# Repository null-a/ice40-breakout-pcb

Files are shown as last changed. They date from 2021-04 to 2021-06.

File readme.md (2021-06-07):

# Lattice iCE40 HX4K breakout / dev board

## Introduction

This KiCAD project contains the design of a break out / dev board for
a Lattice iCE40 HX4K FPGA.

I'm a novice at PCB design, so please don't assume anything here
represents good practice. I was motivated to tackle this after seeing
Matt Venn's [iCE40 board](https://github.com/mattvenn/first-fpga-pcb).
Some elements of the design are based on
the [TinyFPGA BX](https://github.com/tinyfpga/TinyFPGA-BX).

## Features

* SPI flash for configuration.
* On-board clock.
* Powered by 5v from a micro USB connector. Regulators for 3.3v and
  1.2v. Power LED.
* Single output LED.
* 72 GPIO pins broken out. sysCONFIG pins broken out for programming
  the flash. Cold boot config pins broken out.
* The USB data lines are connected to the FPGA. This makes it possible
  to program the board directly over USB using e.g. the TinyFPGA
  bootloader.
* 2 layer PCB.
* Designed for hand assembly.

## Project Log

* 2021-06-07: I now have the
  [TinyFPGA bootloader](https://github.com/tinyfpga/TinyFPGA-Bootloader) working.
* 2021-05-22: Confirmed that I can blink the on-board LED using the
  FPGA. I'm currently using an external programmer to load the
  configuration into the on-board flash. (See [blinky](blinky).)
* 2021-05-12: First
  board
  [assembled](https://www.dropbox.com/s/xi2ujczmzbuk978/?raw=1).
* 2021-05-10: Prototype boards received.
* 2021-04-22:
  [Revision A](https://www.dropbox.com/s/bwuf1rviyvo0iy6/?raw=1) of
  the board completed. Prototype boards ordered.

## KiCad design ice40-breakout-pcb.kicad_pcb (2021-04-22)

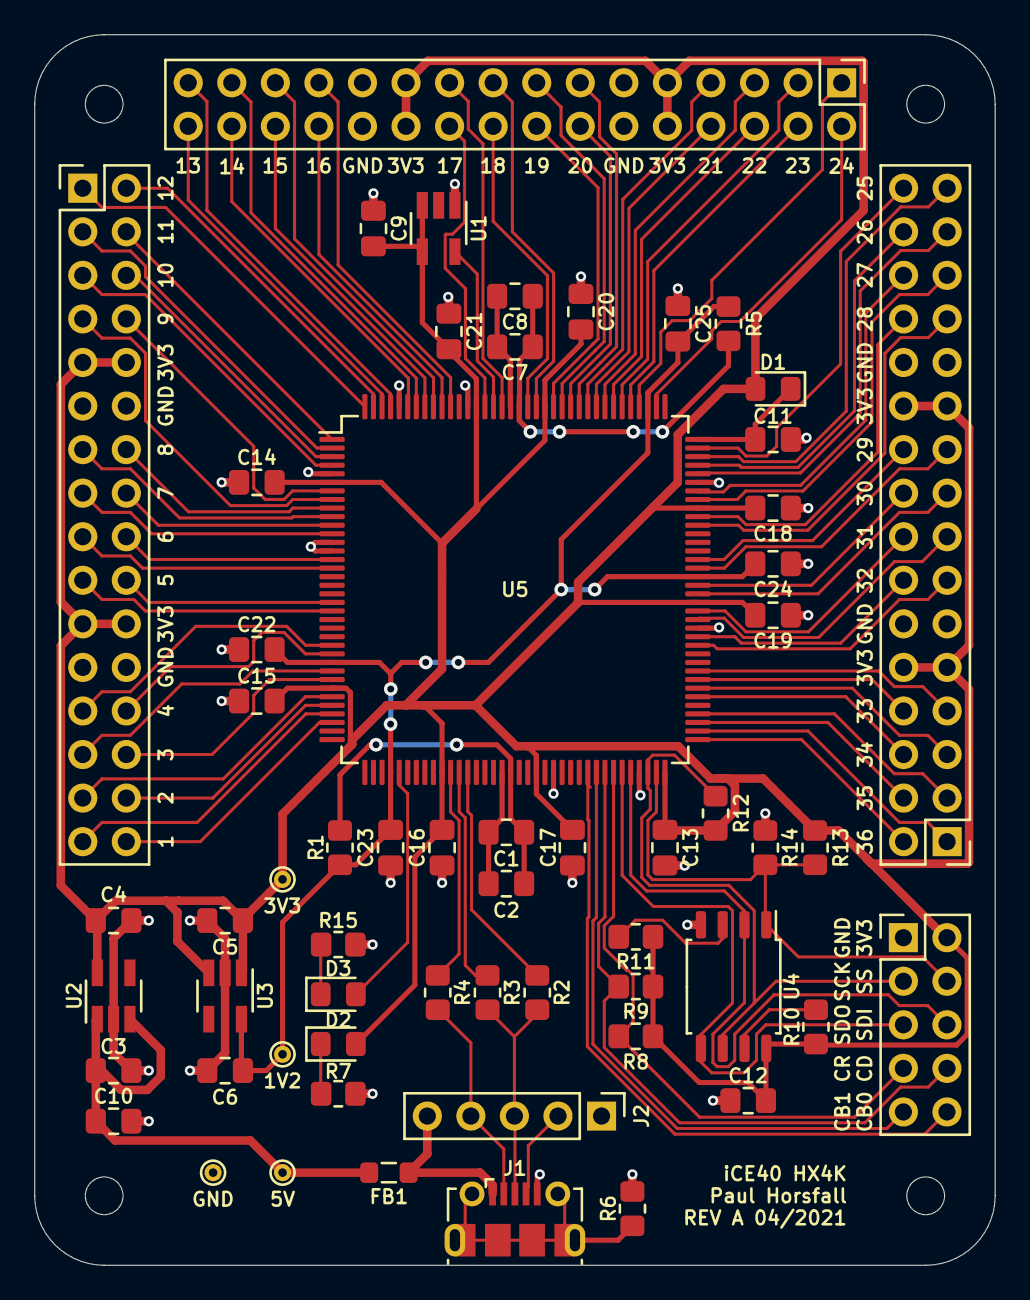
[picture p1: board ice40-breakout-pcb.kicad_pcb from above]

Board: 2 copper layers, 56.0 x 71.8 mm, 59 parts (0 on the bottom side), 103 nets.

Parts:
C1, C7, C10: 10uF; C_0805_2012Metric_Pad1.18x1.45mm_HandSolder
C2, C8, C9, C11, C12, C13, C14, C15, C16, C17, C18, C19, C20, C21, C22, C23, C24, C25: 0.1uF; C_0805_2012Metric_Pad1.18x1.45mm_HandSolder
C3, C4, C5, C6: 1uF; C_0805_2012Metric_Pad1.18x1.45mm_HandSolder
D1: Short; D_0805_2012Metric_Pad1.15x1.40mm_HandSolder
D2, D3: LED; LED_0805_2012Metric_Pad1.15x1.40mm_HandSolder
FB1: 30 ohm; L_0805_2012Metric_Pad1.05x1.20mm_HandSolder
J1: USB_B_Micro; USB_Micro-B_Molex-105017-0001
J2: USB_Break_Out; PinHeader_1x05_P2.54mm_Vertical
J3, J4, J5: Conn_02x16_Odd_Even; PinHeader_2x16_P2.54mm_Vertical
J6: Conn_02x04_Odd_Even; PinHeader_2x05_P2.54mm_Vertical
R1, R5: 100; R_0805_2012Metric_Pad1.20x1.40mm_HandSolder
R2: 1.5K; R_0805_2012Metric_Pad1.20x1.40mm_HandSolder
R3, R4: 68; R_0805_2012Metric_Pad1.20x1.40mm_HandSolder
R6, R10, R11: 0; R_0805_2012Metric_Pad1.20x1.40mm_HandSolder
R7, R15: 330; R_0805_2012Metric_Pad1.20x1.40mm_HandSolder
R8, R9, R12, R13: 10K; R_0805_2012Metric_Pad1.20x1.40mm_HandSolder
R14: NP; R_0805_2012Metric_Pad1.20x1.40mm_HandSolder
TP1, TP2, TP3, TP4: TestPoint; TestPoint_THTPad_D1.0mm_Drill0.5mm
U1: SIT2001BI-S2-33E-12.000000G; SOT-23-5_HandSoldering
U2: TLV73333PDBV; SOT-23-5_HandSoldering
U3: TLV73312PDBV; SOT-23-5_HandSoldering
U4: AT25SF081-SHD-X; SOIC-8_5.23x5.23mm_P1.27mm
U5: ICE40HX4K-TQ144; TQFP-144_20x20mm_P0.5mm

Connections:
+1V2: C6.1, C22.2, C23.2, C24.2, C25.2, R1.1, R5.1, TP3.1, U3.5, U5.27, U5.40, U5.92, U5.111
+3V3: C4.1, C5.1, C9.2, C12.2, C13.1, C14.2, C15.2, C16.2, C17.2, C18.2, C19.2, C20.2, C21.2, D1.2, D2.2, J3.9, J3.10, J3.21, J3.22, J4.9, J4.10, J4.21, J4.22, J5.9, J5.10, J5.21, J5.22, J6.2, R8.1, R9.1, R10.1, R11.1, R12.1, R13.1, TP2.1, U1.3, U1.4, U2.5, U3.1, U3.3, U4.8, U5.6, U5.30, U5.46, U5.57, U5.72, U5.89, U5.100, U5.123, U5.131
+5V: C3.1, C10.1, FB1.2, TP1.1, U2.1, U2.3
CDONE: J6.8, R9.2, U5.65
CLK: U1.5, U5.129
CRESET: J6.7, R8.2, U5.66
GND: C3.2, C4.2, C5.2, C6.2, C9.1, C10.2, C11.2, C12.1, C13.2, C14.1, C15.1, C16.1, C17.1, C18.1, C19.1, C20.1, C21.1, C22.1, C23.1, C24.1, C25.1, J1.5, J2.1, J3.11, J3.12, J3.23, J3.24, J4.11, J4.12, J4.23, J4.24, J5.11, J5.12, J5.23, J5.24, J6.1, R6.2, R7.2, R14.1, R15.2, TP4.1, U1.1, U2.2, U3.2, U4.4, U5.5, U5.13, U5.14, U5.59, U5.69, U5.86, U5.103, U5.132, U5.140
GNDPLL0: C1.2, C2.2, U5.53
GNDPLL1: C7.2, C8.2, U5.127
LED: D3.2, U5.41
unnamed: D2.1, R7.1
unnamed: D3.1, R15.1
unnamed: FB1.1, J1.1, J2.5
unnamed: J1.2, J2.4, R4.2
unnamed: J1.3, J2.3, R2.2, R3.2
unnamed: J1.4, J2.2
unnamed: J1.6, R6.1
unnamed: R10.2, U4.7
unnamed: R11.2, U4.3
SPI_MISO: J6.6, U4.2, U5.68
SPI_MOSI: J6.5, U4.5, U5.67
SPI_SCK: J6.3, R12.2, U4.6, U5.70
SPI_SS: J6.4, R13.2, R14.2, U4.1, U5.71
USB_N: R4.1, U5.47
USB_P: R3.1, U5.48
USB_PU: R2.1, U5.49
VCCPLL0: C1.1, C2.1, R1.2, U5.54
VCCPLL1: C7.1, C8.1, R5.2, U5.126
VPP_2V5: C11.1, D1.1, U5.108
cbsel0: J6.10, U5.63
cbsel1: J6.9, U5.64
gp_a_1: J3.1, U5.144
gp_a_2: J3.2, U5.143
gp_a_3: J3.3, U5.2
gp_a_4: J3.4, U5.1
gp_a_5: J3.5, U5.4
gp_a_6: J3.6, U5.3
gp_a_7: J3.7, U5.8
gp_a_8: J3.8, U5.7
gp_a_9: J3.13, U5.10
gp_a_10: J3.14, U5.9
gp_a_11: J3.15, U5.12
gp_a_12: J3.16, U5.11
gp_a_13: J3.17, U5.16
gp_a_14: J3.18, U5.15
gp_a_15: J3.19, U5.21
gp_a_16: J3.20, U5.20
gp_a_17: J3.25, U5.25
gp_a_18: J3.26, U5.26
gp_a_19: J3.27, U5.28
gp_a_20: J3.28, U5.29
gp_a_21: J3.29, U5.31
gp_a_22: J3.30, U5.32
gp_a_23: J3.31, U5.33
gp_a_24: J3.32, U5.34
gp_b_1: J5.1, U5.112
gp_b_2: J5.2, U5.110
gp_b_3: J5.3, U5.114
gp_b_4: J5.4, U5.113
gp_b_5: J5.5, U5.116
gp_b_6: J5.6, U5.115
gp_b_7: J5.7, U5.118
gp_b_8: J5.8, U5.117
gp_b_9: J5.13, U5.119
gp_b_10: J5.14, U5.120
gp_b_11: J5.15, U5.121
gp_b_12: J5.16, U5.122
gp_b_13: J5.17, U5.124
gp_b_14: J5.18, U5.125
gp_b_15: J5.19, U5.128
gp_b_16: J5.20, U5.130
gp_b_17: J5.25, U5.134
gp_b_18: J5.26, U5.135
gp_b_19: J5.27, U5.136
gp_b_20: J5.28, U5.137
gp_b_21: J5.29, U5.138
gp_b_22: J5.30, U5.139
gp_b_23: J5.31, U5.141
gp_b_24: J5.32, U5.142
gp_c_1: J4.1, U5.74
gp_c_2: J4.2, U5.73
gp_c_3: J4.3, U5.76
gp_c_4: J4.4, U5.75
gp_c_5: J4.5, U5.79
gp_c_6: J4.6, U5.78
gp_c_7: J4.7, U5.81
gp_c_8: J4.8, U5.80
gp_c_9: J4.13, U5.84
gp_c_10: J4.14, U5.85
gp_c_11: J4.15, U5.87
gp_c_12: J4.16, U5.88
gp_c_13: J4.17, U5.90
gp_c_14: J4.18, U5.91
gp_c_15: J4.19, U5.93
gp_c_16: J4.20, U5.94
gp_c_17: J4.25, U5.98
gp_c_18: J4.26, U5.99
gp_c_19: J4.27, U5.101
gp_c_20: J4.28, U5.102
gp_c_21: J4.29, U5.104
gp_c_22: J4.30, U5.105
gp_c_23: J4.31, U5.106
gp_c_24: J4.32, U5.107

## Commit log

2021-04-16 First pass at schema entry.
    [ice40-breakout-pcb.kicad_pcb, ice40-breakout-pcb.sch]
2021-04-16 Initial component placement.
    [ice40-breakout-pcb.kicad_pcb]
2021-04-16 Allocate FPGA pins for LED & USB.
    [ice40-breakout-pcb.kicad_pcb, ice40-breakout-pcb.sch]
2021-04-18 Make it easier to route PLL grounds.
    [ice40-breakout-pcb.kicad_pcb]
2021-04-18 Re-position SCK pull-up to give SS a path to connector.
    [ice40-breakout-pcb.kicad_pcb]
2021-04-18 Place cap next to power pin.
    [ice40-breakout-pcb.kicad_pcb]
2021-04-18 Allocate FPGA pin for LED.
    [ice40-breakout-pcb.kicad_pcb, ice40-breakout-pcb.sch]
2021-04-18 Adjust component placement for easy soldering.
    [ice40-breakout-pcb.kicad_pcb]
2021-04-19 Tweak board set-up. (Trace widths, etc.)
    [ice40-breakout-pcb.kicad_pcb]
2021-04-19 First pass at routing for core.
    [ice40-breakout-pcb.kicad_pcb]
2021-04-19 Experimenting with external connector configuration.
    [ice40-breakout-pcb.kicad_pcb, ice40-breakout-pcb.sch]
2021-04-19 Fine adjustment of board outline.
    [ice40-breakout-pcb.kicad_pcb]
2021-04-19 Adjust power to make it easier to break out more signals.
    [ice40-breakout-pcb.kicad_pcb]
2021-04-19 Cosmetic tweak.
    [ice40-breakout-pcb.kicad_pcb]
2021-04-19 Move SPI connector to make room for mounting hole.
    [ice40-breakout-pcb.kicad_pcb]
2021-04-20 Initial routing of GPIO.
    [ice40-breakout-pcb.kicad_pcb, ice40-breakout-pcb.sch]
2021-04-20 Reposition voltage regulators for more compact layout.
    [ice40-breakout-pcb.kicad_pcb]
2021-04-20 Shorten the board.
    [ice40-breakout-pcb.kicad_pcb]
2021-04-20 Experimental mounting hole in top-right.
    [ice40-breakout-pcb.kicad_pcb]
2021-04-20 Re-jig bottom right of layout to put connector on edge of board.
    [ice40-breakout-pcb.kicad_pcb, ice40-breakout-pcb.sch]
2021-04-20 Bring CBSEL lines out to connector.
    [ice40-breakout-pcb.kicad_pcb, ice40-breakout-pcb.sch]
2021-04-20 Reduce board length to match length of connectors.
    [ice40-breakout-pcb.kicad_pcb]
2021-04-20 Add remaining mounting holes.
    [ice40-breakout-pcb.kicad_pcb]
2021-04-20 Make ERC pass in schematic.
    [ice40-breakout-pcb.sch]
2021-04-21 Route GBIN pins where possible.
    [ice40-breakout-pcb.kicad_pcb, ice40-breakout-pcb.sch]
2021-04-21 Make 3v3 power tracks wider in most places.
    [ice40-breakout-pcb.kicad_pcb]
2021-04-21 Have LEDs orientated the same way.
    [ice40-breakout-pcb.kicad_pcb]
2021-04-21 Fix-up USB routing.
    [ice40-breakout-pcb.kicad_pcb]
2021-04-21 Add missing 3v3 route.
    [ice40-breakout-pcb.kicad_pcb]
2021-04-21 Use wider trace for 3v3 power to external connector & add GND plane.
    [ice40-breakout-pcb.kicad_pcb]
2021-04-21 Add ground vias.
    [ice40-breakout-pcb.kicad_pcb]
2021-04-21 Connect USB socket pads to keep DRC happy.
    [ice40-breakout-pcb.kicad_pcb]
2021-04-21 Fix-up front silk screen.
    [ice40-breakout-pcb.kicad_pcb]
2021-04-21 Fix component spacing inline with rest of layout.
    [ice40-breakout-pcb.kicad_pcb]
2021-04-21 Label main external connectors.
    [ice40-breakout-pcb.kicad_pcb]
2021-04-21 Re-jig bottom right corner to accommodate labels.
    [ice40-breakout-pcb.kicad_pcb]
2021-04-21 Label SPI connector.
    [ice40-breakout-pcb.kicad_pcb]
2021-04-21 Fix wonky test point placement.
    [ice40-breakout-pcb.kicad_pcb]
2021-04-21 Add name, date, revision, etc. to silk screen.
    [ice40-breakout-pcb.kicad_pcb]
2021-04-21 Re-fill ground plane.
    [ice40-breakout-pcb.kicad_pcb]
2021-04-22 Tweak silk screen text.
    [ice40-breakout-pcb.kicad_pcb]
2021-04-22 Remove stale TODO note.
    [ice40-breakout-pcb.sch]
2021-04-22 Add missing component values.
    [ice40-breakout-pcb.kicad_pcb, ice40-breakout-pcb.sch]
